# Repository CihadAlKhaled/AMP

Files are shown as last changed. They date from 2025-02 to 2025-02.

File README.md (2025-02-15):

# Acceleration Monitor PCB (AMP)

## Background 
The AMP tracks acceleration in the x, y, and z-axis in units of Earth's gravitational acceleration (g). 

## Design
The PCB is powered via a USB connection, which supplies both power and data communication to the computer. An MPU6050 tracks acceleration, which is read by an RP2040 microcontroller over an I²C interface. The computer receives this data and displays it in a console. A 1x2 connector allows the AMP to enter **BOOTSEL** mode when shorted. Additionally, a crystal oscillator provides a stable clock signal for timing operations.

The AMP was designed using KiCad:

### Schematics Design

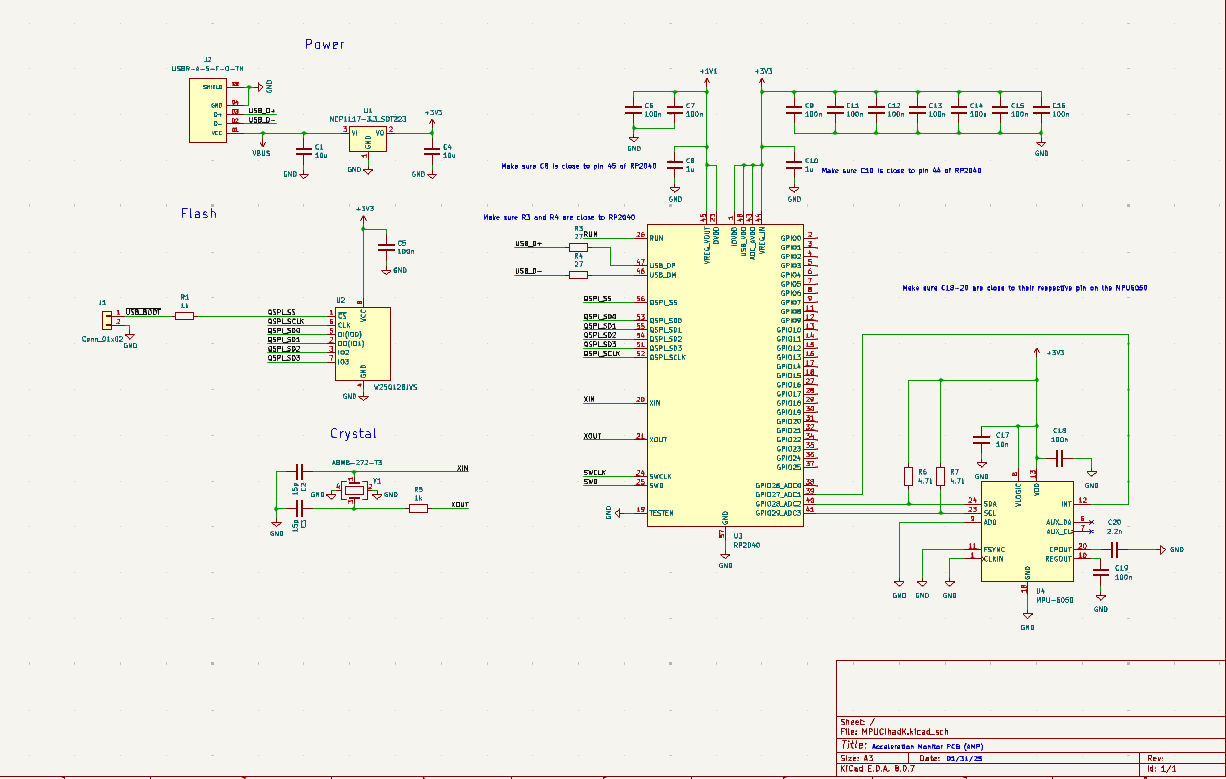
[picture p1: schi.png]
  
**Figure 1.0**  

### PCB Design

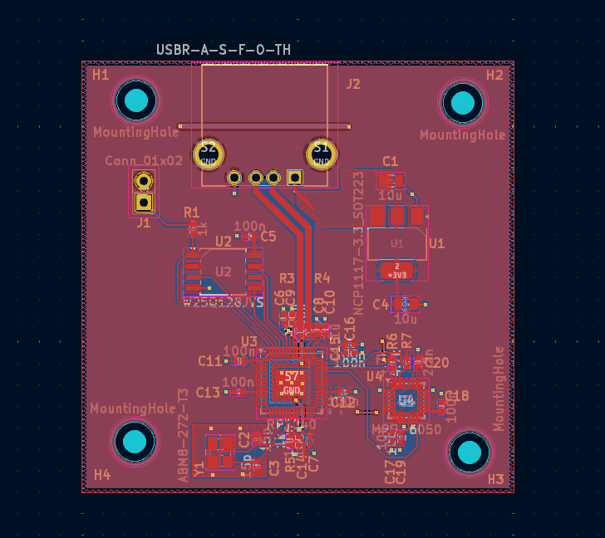
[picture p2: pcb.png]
  
**Figure 1.1**  

### 3D Rendering of AMP

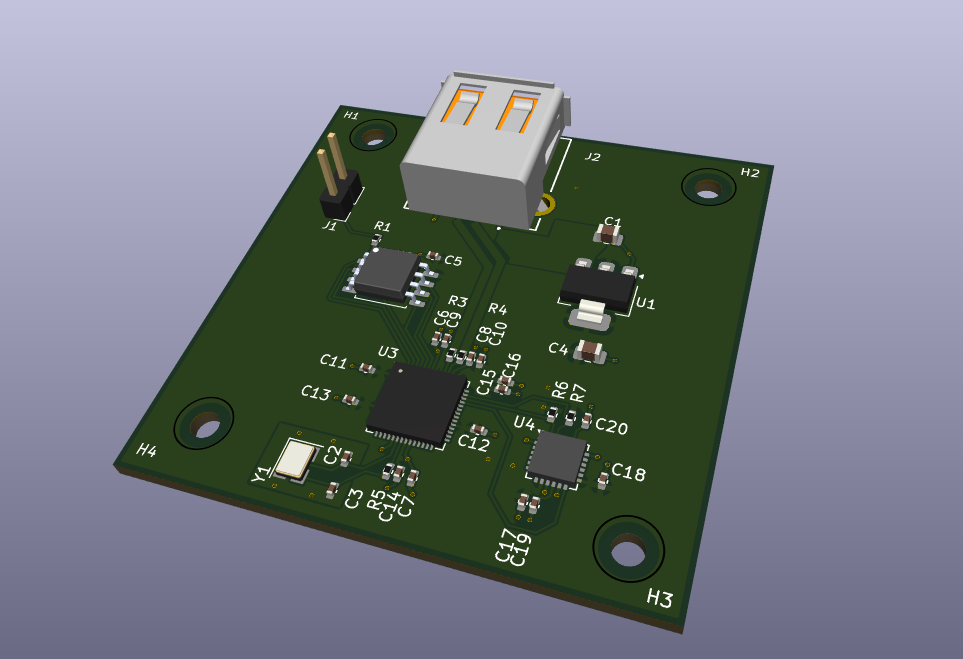
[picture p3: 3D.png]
  
**Figure 1.2**  

## Hardware
All parts were bought and put together by [JLCPCB](https://jlcpcb.com/). **Table 2.0** has a list of all the components used in the AMP.  

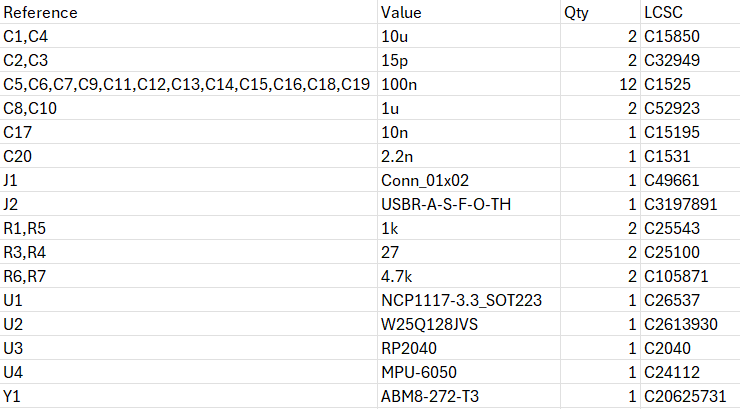
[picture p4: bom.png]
  
**Table 2.0**  

## Physical PCB
The board arrived, and in **Figure 3.1**, the 1x2 connector is shorted using the red wire, thus in **BOOTSEL** mode.  

### AMP  
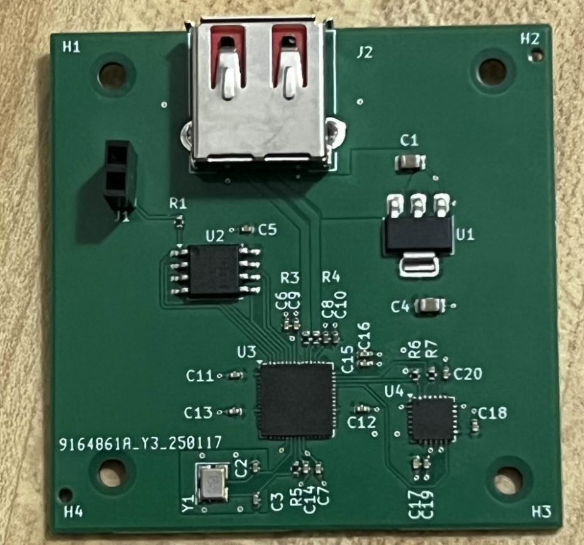
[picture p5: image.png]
 

**Figure 3.0** 

### BOOTSEL Mode  
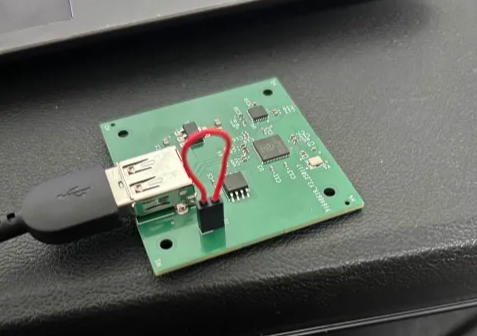
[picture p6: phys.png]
  
**Figure 3.1**  

## Software
The software was programmed in MicroPython and uploaded to the RP2040's file system. The software configures the I²C interface by initializing the RP2040's GPIO28 and GPIO29 to the SDA and SCL of the MPU6050. The MPU6050 has a standardized address that the RP2040 communicates with to wake it up and start collecting acceleration data from the AMP.  

### Code uploaded onto the AMP  
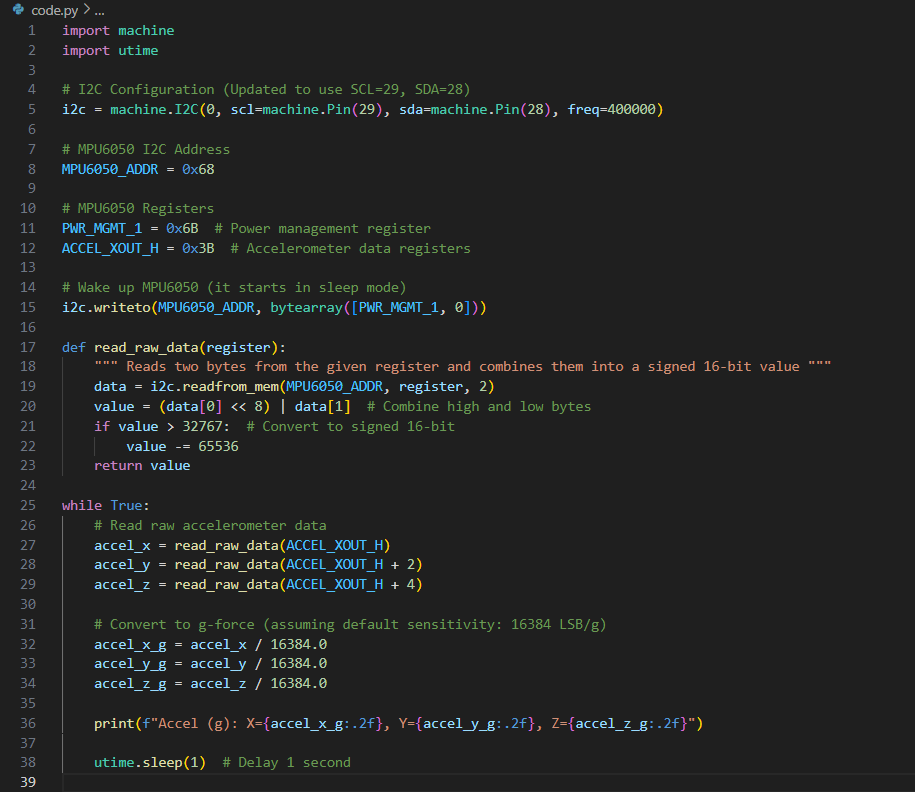
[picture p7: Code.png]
  
**Figure 4.0**  

### Output
The code displays the data from the AMP onto the console, showing the x, y, and z components of the acceleration in units of g.  

### Stationary

When the AMP is placed stationary and upright, the z component represents the Earth's gravity on the AMP (~1g = 9.8 m/s²), while x and y are close to zero g. Shown in **Figure 4.1**, there is a slight discrepancy due to the AMP not being perfectly upright, causing Earth's gravity to also appear in the x and y components. Additionally, some noise is present in the readings.  

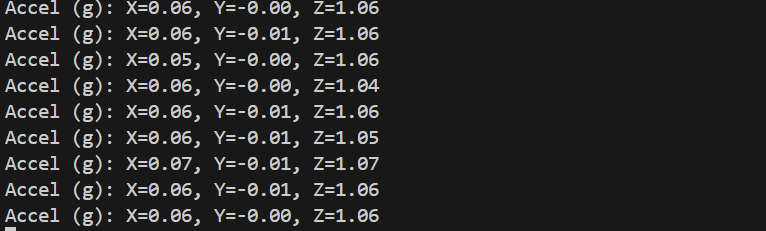
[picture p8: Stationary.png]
  
**Figure 4.1**  

### AMP says WOOF!

The AMP was getting antsy staying stationary, so it went on a walk in the negative y direction while slowly increasing acceleration, as shown in **Figure 4.2**.  

  
**Figure 4.2**  

### AMP goes up, up, up... and back down?

The AMP being thrown into the air was mimicked (no broken PCB today!). The z-axis shows the acceleration of it going up and then coming back down, as shown in **Figure 4.3**.  

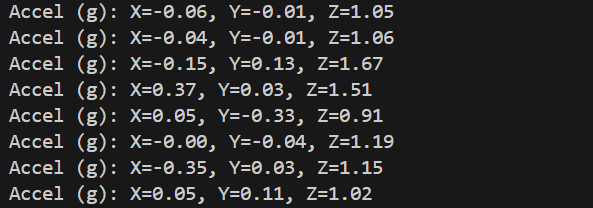
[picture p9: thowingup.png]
  
**Figure 4.3**  

### "Around we go"

The AMP was swung around in a circle, and the y-axis represents the measured centripetal acceleration of the PCB, as shown in **Figure 4.4**. The centripetal acceleration could be used to calculate the tension of the wire connecting the computer and the AMP.  

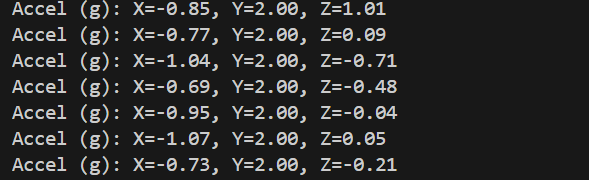
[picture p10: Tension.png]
  
**Figure 4.4**  

## Challenges 
The AMP project was my first PCB design, making it a challenging but valuable learning experience. Understanding how each chip interacted with the others was challenging, and extracting relevant information from datasheets was a struggle in itself. Learning how to **read and interpret datasheets** is a skill I need to continue developing if I want to keep making PCBs.

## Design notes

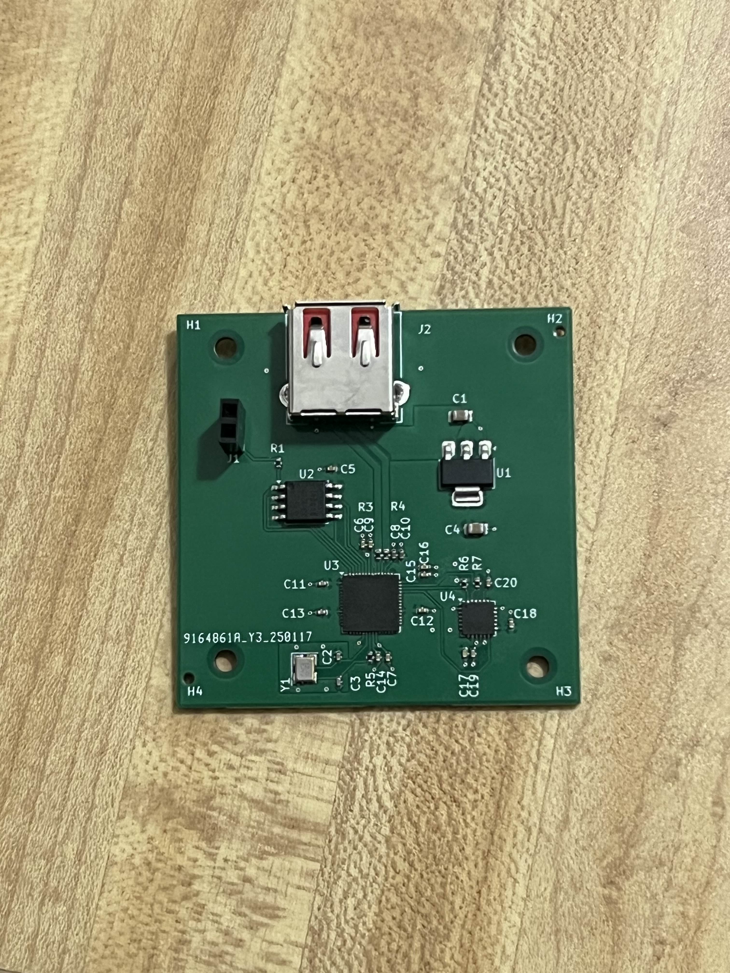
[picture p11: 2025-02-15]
AMP.jpg

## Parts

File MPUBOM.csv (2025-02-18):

Reference | Value | Datasheet | Footprint | Qty | DNP | LCSC | Link
C1,C4 | 10u | https://www.lcsc.com/datasheet/lcsc_datasheet_2208231630_Samsung-Electro-Mechanics-CL05A106MQ5NUNC_C15525.pdf | Capacitor_SMD:C_0805_2012Metric | 2 |  | C15525 | https://jlcpcb.com/partdetail/C15525
C2,C3 | 15p | https://www.lcsc.com/datasheet/lcsc_datasheet_2304140030_Samsung-Electro-Mechanics-CL05C100JB5NNNC_C32949.pdf | Capacitor_SMD:C_0402_1005Metric | 2 |  | C32949 | https://jlcpcb.com/partdetail/C32949
C5,C6,C7,C9,C11,C12,C13,C14,C15,C16,C18,C19 | 100n | https://www.lcsc.com/datasheet/lcsc_datasheet_2304140030_Samsung-Electro-Mechanics-CL05B104KO5NNNC_C1525.pdf | Capacitor_SMD:C_0402_1005Metric | 12 |  | C1525 | https://jlcpcb.com/partdetail/C1525
C8,C10 | 1u | https://www.lcsc.com/datasheet/lcsc_datasheet_2304140030_Samsung-Electro-Mechanics-CL05A105KA5NQNC_C52923.pdf | Capacitor_SMD:C_0402_1005Metric | 2 |  | C52923 | https://jlcpcb.com/partdetail/C52923
C17 | 10n | https://www.lcsc.com/datasheet/lcsc_datasheet_2304140030_Samsung-Electro-Mechanics-CL05B103KB5NNNC_C15195.pdf | Capacitor_SMD:C_0402_1005Metric | 1 |  | C15195 | https://jlcpcb.com/partdetail/15869-CL05B103KB5NNNC/C15195
C20 | 2.2n | https://www.lcsc.com/datasheet/lcsc_datasheet_2304140030_FH--Guangdong-Fenghua-Advanced-Tech-0402B222K500NT_C1531.pdf | Capacitor_SMD:C_0402_1005Metric | 1 |  | C1531 | https://jlcpcb.com/partdetail/1883-0402B222K500NT/C1531
J1 | Conn_01x02 | https://www.lcsc.com/datasheet/lcsc_datasheet_2304140030_BOOMELE-Boom-Precision-Elec-2-54-1-2P_C49661.pdf | Connector_PinHeader_2.54mm:PinHeader_1x02_P2.54mm_Vertical | 1 |  | C49661 | https://jlcpcb.com/partdetail/50669-2_54_1_2P/C49661
J2 | USBR-A-S-F-O-TH | https://wmsc.lcsc.com/wmsc/upload/file/pdf/v2/lcsc/2401291333_Samtec-USBR-A-S-F-O-TH_C3197891.pdf | USBR-A-S-F-O-TH (1):SAMTEC_USBR-A-S-F-O-TH | 1 |  | C3197891 | https://jlcpcb.com/partdetail/Samtec-USBR_A_S_F_OTH/C3197891
R1,R5 | 1k | https://www.lcsc.com/datasheet/lcsc_datasheet_2205311845_UNI-ROYAL-Uniroyal-Elec-0402WGJ0102TCE_C25543.pdf | Resistor_SMD:R_0402_1005Metric | 2 |  | C25543 | https://jlcpcb.com/partdetail/26286-0402WGJ0102TCE/C25543
R3,R4 | 27 | https://www.lcsc.com/datasheet/lcsc_datasheet_2205311900_UNI-ROYAL-Uniroyal-Elec-0402WGF270JTCE_C25100.pdf | Resistor_SMD:R_0402_1005Metric | 2 |  | C25100 | https://jlcpcb.com/partdetail/25843-0402WGF270JTCE/C25100
R6,R7 | 4.7k | https://www.lcsc.com/datasheet/lcsc_datasheet_2304140030_YAGEO-RC0402FR-074K7L_C105871.pdf | Resistor_SMD:R_0402_1005Metric | 2 |  | C105871 | https://jlcpcb.com/parts/componentSearch?searchTxt=4.7k%200402
U1 | NCP1117-3.3_SOT223 | http://www.onsemi.com/pub_link/Collateral/NCP1117-D.PDF | Package_TO_SOT_SMD:SOT-223-3_TabPin2 | 1 |  | C26537 | https://jlcpcb.com/partdetail/Onsemi-NCP1117ST33T3G/C26537
U2 | W25Q128JVS | http://www.winbond.com/resource-files/w25q128jv_dtr%20revc%2003272018%20plus.pdf | Package_SO:SOIC-8_5.23x5.23mm_P1.27mm | 1 |  | C2613930 | https://jlcpcb.com/partdetail/WinbondElec-W25Q128JVSIM/C2613930
U3 | RP2040 | https://datasheets.raspberrypi.com/rp2040/rp2040-datasheet.pdf | Package_DFN_QFN:QFN-56-1EP_7x7mm_P0.4mm_EP3.2x3.2mm | 1 |  | C2040 | https://jlcpcb.com/partdetail/RaspberryPi-RP2040/C2040
U4 | MPU-6050 | https://invensense.tdk.com/wp-content/uploads/2015/02/MPU-6000-Datasheet1.pdf | Sensor_Motion:InvenSense_QFN-24_4x4mm_P0.5mm | 1 |  | C24112 | https://jlcpcb.com/partdetail/TdkInvensense-MPU6050/C24112
Y1 | ABM8-272-T3 | https://jlcpcb.com/api/file/downloadByFileSystemAccessId/8559470777180311552 | Crystal:Crystal_SMD_3225-4Pin_3.2x2.5mm | 1 |  | C20625731 | https://jlcpcb.com/partdetail/AbraconLlc-ABM8_272T3/C20625731

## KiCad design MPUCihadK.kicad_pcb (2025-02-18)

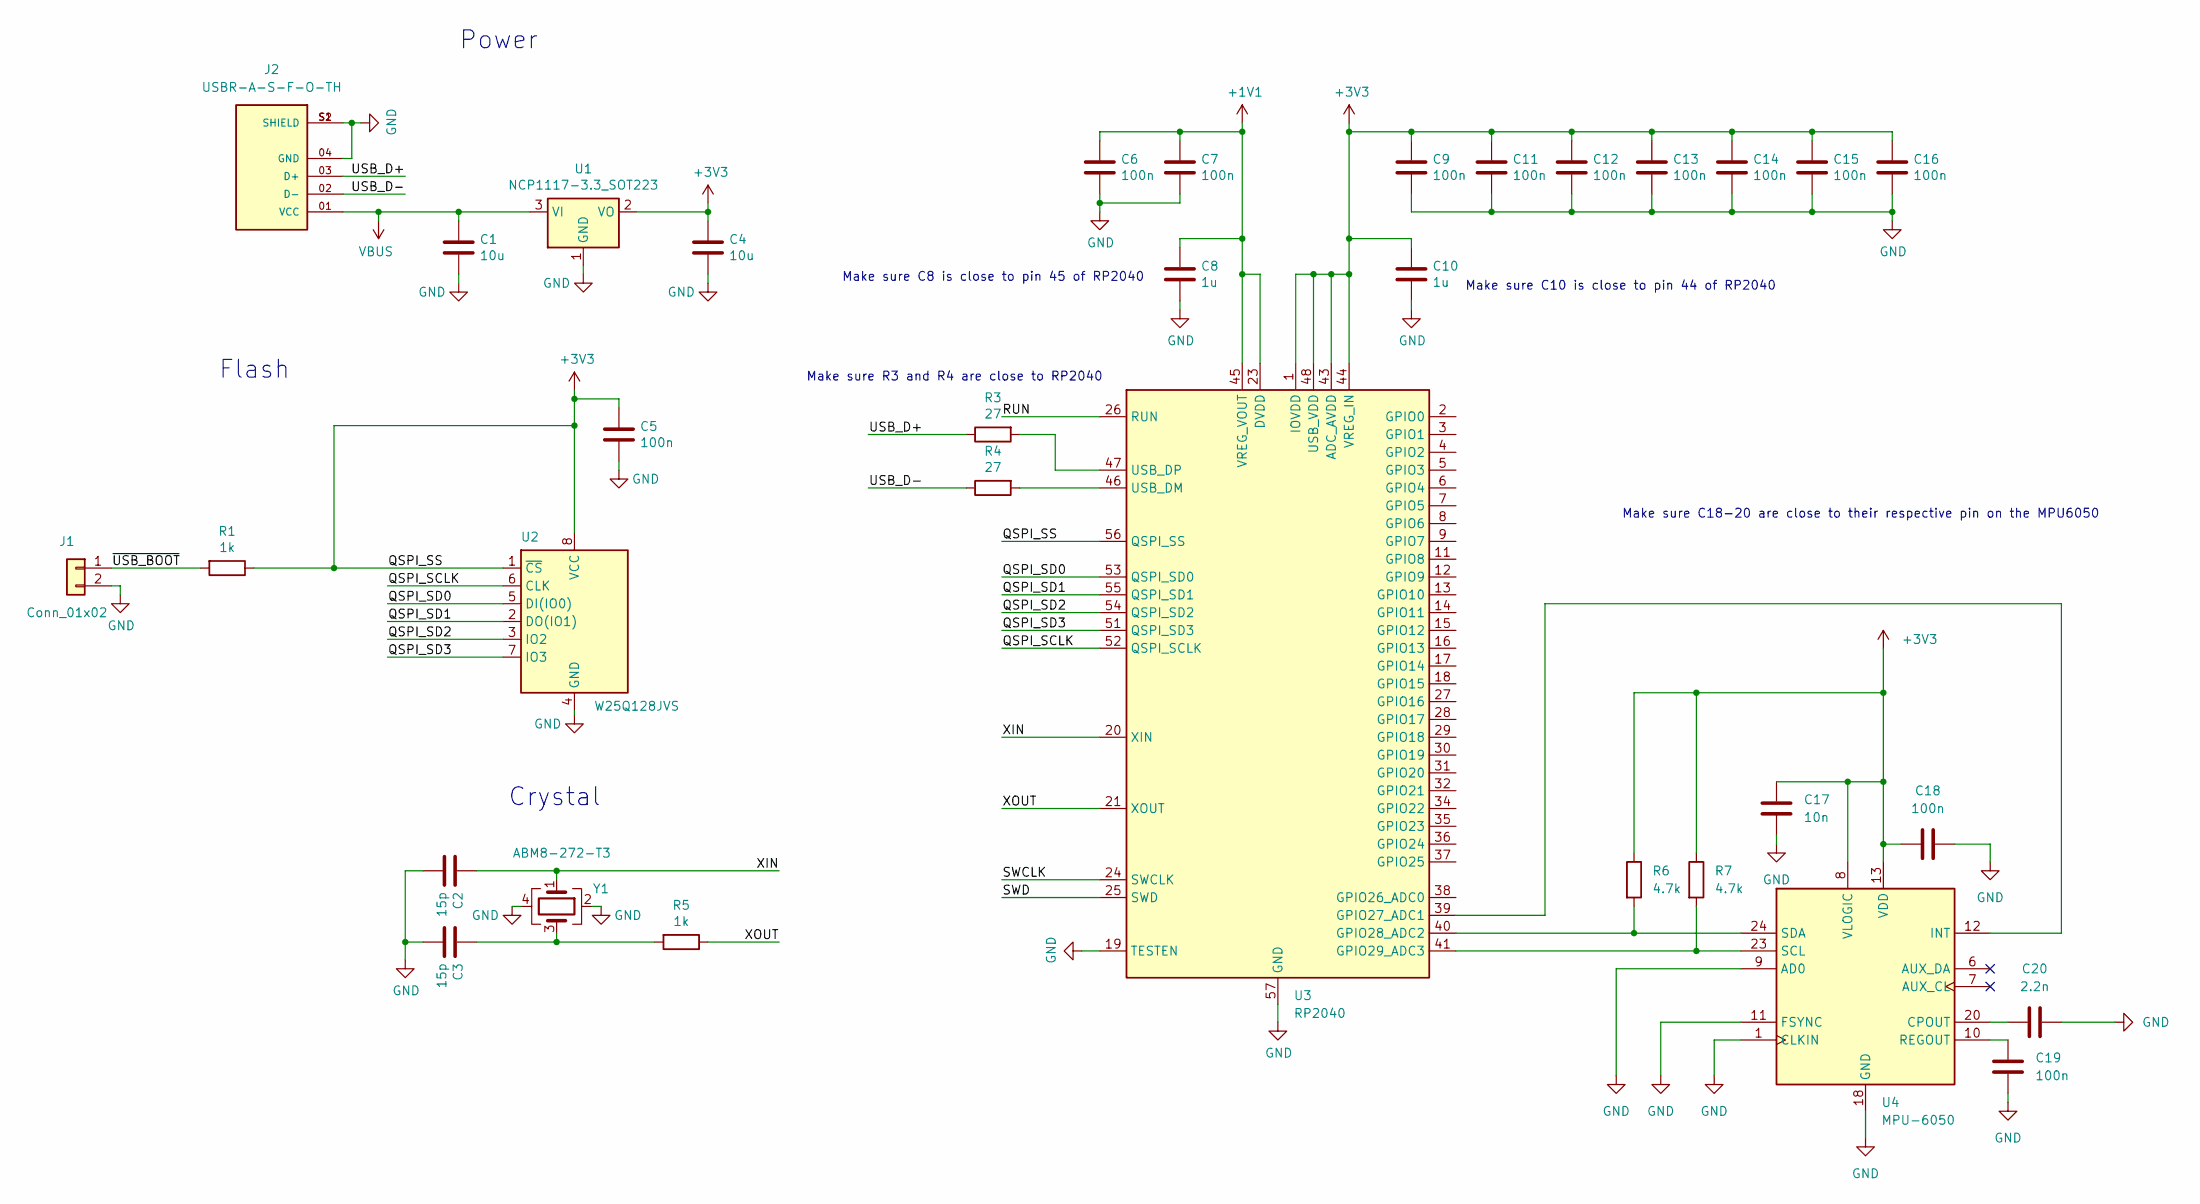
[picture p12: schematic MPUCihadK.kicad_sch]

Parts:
C1, C4: 10u; C_0805_2012Metric; LCSC C15525
C2, C3: 15p; C_0402_1005Metric; LCSC C32949
C5, C6, C7, C9, C11, C12, C13, C14, C15, C16, C18, C19: 100n; C_0402_1005Metric; LCSC C1525
C8, C10: 1u; C_0402_1005Metric; LCSC C52923
C17: 10n; C_0402_1005Metric; LCSC C15195
C20: 2.2n; C_0402_1005Metric; LCSC C1531
J1: Conn_01x02; PinHeader_1x02_P2.54mm_Vertical; LCSC C49661
J2: USBR-A-S-F-O-TH; SAMTEC_USBR-A-S-F-O-TH; PARTREV L; LCSC C3197891
R1, R5: 1k; R_0402_1005Metric; LCSC C25543
R3, R4: 27; R_0402_1005Metric; LCSC C25100
R6, R7: 4.7k; R_0402_1005Metric; LCSC C105871
U1: NCP1117-3.3_SOT223; SOT-223-3_TabPin2; LCSC C26537
U2: W25Q128JVS; SOIC-8_5.23x5.23mm_P1.27mm; LCSC C2613930
U3: RP2040; QFN-56-1EP_7x7mm_P0.4mm_EP3.2x3.2mm; LCSC C2040
U4: MPU-6050; InvenSense_QFN-24_4x4mm_P0.5mm; LCSC C24112
Y1: ABM8-272-T3; Crystal_SMD_3225-4Pin_3.2x2.5mm; LCSC C20625731

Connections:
+1V1: C6.1, C7.1, C8.1, U3.23 (DVDD), U3.45 (VREG_VOUT), U3.50 (DVDD)
/QSPI_SCLK: U2.6 (CLK), U3.52 (QSPI_SCLK)
/QSPI_SD0: U2.5 (DI(IO0)), U3.53 (QSPI_SD0)
/QSPI_SD1: U2.2 (DO(IO1)), U3.55 (QSPI_SD1)
/QSPI_SD2: U2.3 (IO2), U3.54 (QSPI_SD2)
/QSPI_SD3: U2.7 (IO3), U3.51 (QSPI_SD3)
/RUN: U3.26 (RUN)
/SWCLK: U3.24 (SWCLK)
/SWD: U3.25 (SWD)
/USB_D+: J2.03 (D+), R3.1
/USB_D-: J2.02 (D-), R4.1
/XIN: C2.1, U3.20 (XIN), Y1.1
/XOUT: R5.1, U3.21 (XOUT)
/~USB_BOOT: J1.1, R1.2
GND: C1.2, C2.2, C3.2, C4.2, C5.2, C6.2, C7.2, C8.2, C9.2, C10.2, C11.2, C12.2, C13.2, C14.2, C15.2, C16.2, C17.2, C18.2, C19.2, C20.2, J1.2, J2.04 (GND), J2.S1 (SHIELD), J2.S2 (SHIELD), U1.1 (GND), U2.4 (GND), U3.19 (TESTEN), U3.57 (GND), U4.1 (CLKIN), U4.9 (AD0), U4.11 (FSYNC), U4.18 (GND), Y1.2, Y1.4
unnamed: C3.1, R5.2, Y1.3
unnamed: U3.39 (GPIO27_ADC1), U4.12 (INT)
unnamed: R6.2, U3.40 (GPIO28_ADC2), U4.24 (SDA)
unnamed: R7.2, U3.41 (GPIO29_ADC3), U4.23 (SCL)
unnamed: R4.2, U3.46 (USB_DM)
unnamed: R3.2, U3.47 (USB_DP)
unnamed: C20.1, U4.20 (CPOUT)
unnamed: C19.1, U4.10 (REGOUT)
VBUS: C1.1, J2.01 (VCC), U1.3 (VI)

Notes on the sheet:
Make sure C8 is close to pin 45 of RP2040
Make sure C10 is close to pin 44 of RP2040
Make sure C18-20 are close to their respective pin on the MPU6050
Make sure R3 and R4 are close to RP2040
Crystal
Power
Flash

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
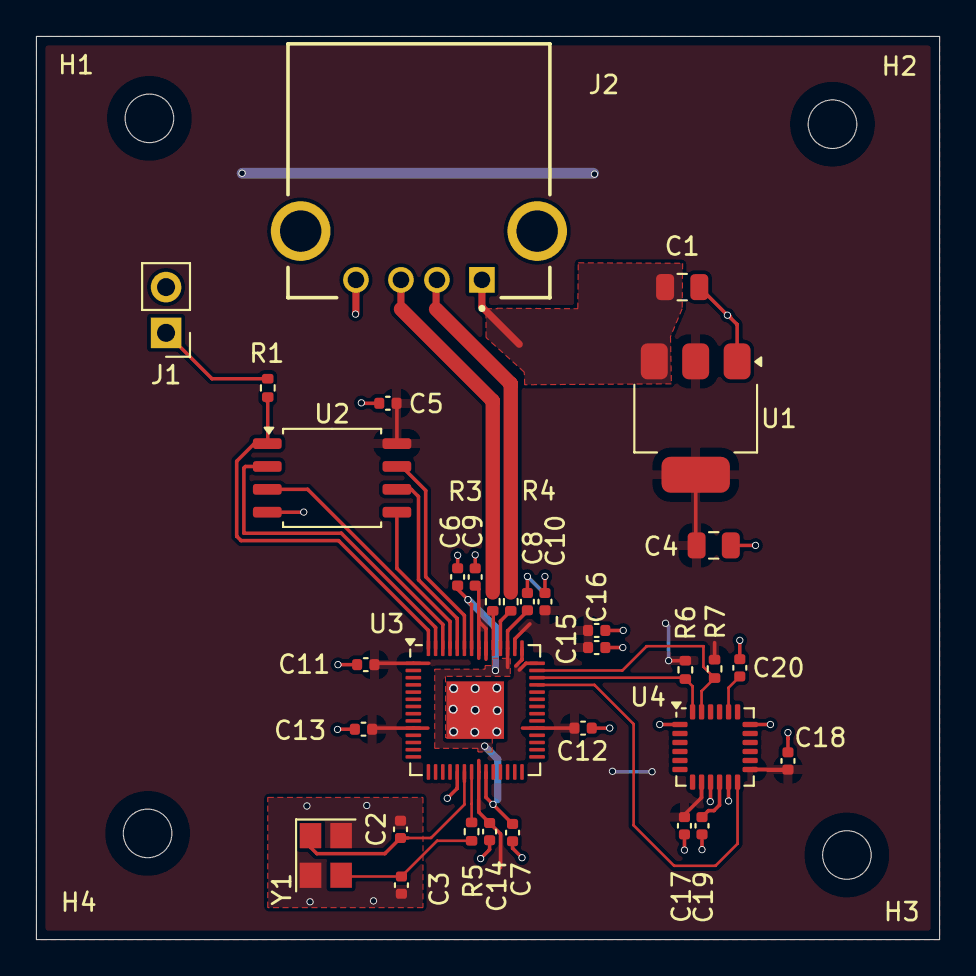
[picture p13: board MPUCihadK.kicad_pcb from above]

Board: 2 copper layers, 50.2 x 50.2 mm, 37 parts (0 on the bottom side), 23 nets.

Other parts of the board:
H1, H2, H3, H4: MountingHole; MountingHole_2.7mm_M2.5
